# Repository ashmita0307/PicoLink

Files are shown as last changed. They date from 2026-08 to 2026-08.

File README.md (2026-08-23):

# PicoLink
An RP2040-based project for VGA graphics generation and USB composite device implementation.

## Table of Contents

  - [PicoLink](#picolink)
  - [Table of Contents](#table-of-contents)
  - [About The Project](#about-the-project)
  - [Features](#features)
  - [Project Workflow](#project-workflow)
  - [Hardware Used](#hardware-used)
  - [Breadboard Testing](#breadboard-testing)
  - [PCB Model](#pcb-model)
  - [Software Used](#software-used)
  - [Future Work](#future-work)
  - [Contributors](#contributors)
  - [Resources](#resources)
  - [Acknowledgements](#acknowledgements)

## About The Project
**PicoLink** is an RP2040-based project focused on **VGA graphics generation** and **USB communication**. It uses **PIO and DMA** for efficient VGA output and implements a **USB composite device with HID and CDC interfaces**.

## Features

- VGA output using RP2040
- Custom VGA graphics library
- Increased color support
- PIO-based VGA signal generation
- DMA-assisted data transfer
- Custom PCB design
- Space Invaders game
- Pacman game
## Project Workflow

#### Research

* Understanding VGA standards, timing, and signal generation
* Studying the RP2040's PIO and DMA peripherals
* Reviewing existing VGA libraries and RP2040 implementations

#### VGA Graphics Development

* Implementing VGA signal generation using PIO
* Developing a custom VGA graphics library
* Implementing framebuffer-based graphics
* Increasing color support and optimizing memory usage
* Testing VGA output on a monitor

#### PCB Design

* Designing the PicoLink PCB around the RP2040
* Designing the VGA interface and USB connections
* Routing the PCB while considering signal integrity and hardware constraints
* Finalizing the PCB for manufacturing
#### USB Development

* Implementing USB HID functionality
* Implementing USB CDC communication
* Creating and understanding the required USB descriptors
* Integrating HID and CDC as a composite USB device

#### Game Development & Testing

* Developing **Sngpace Invaders & Pacman** using the custom VGA graphics library
* Integrating the game with the PicoLink hardware
* Testing VGA output, USB communication, and overall system performance
* Debugging and optimizing the final implementation

## Hardware Used

| Components | Description |
| --- | --- |
| [RP2040-Mitrocontroller](https://robu.in/product/raspberry-pi-pico/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) | Microcontroller |
| [15-Pin VGA Connector](https://robu.in/product/x0615ft7b1-xkb-15p-female-d-sub-3-d-sub-vga-connectors-rohs/)  | VGA-connector |
| [33O ohm Resistors](https://robu.in/product/330-ohm-1-4w-1206-surface-mount-chip-resistor-pack-of-100/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) | Resistor |

## Breadboard Testing
- View of Breadboard VGA Connections:   
<p align="left">
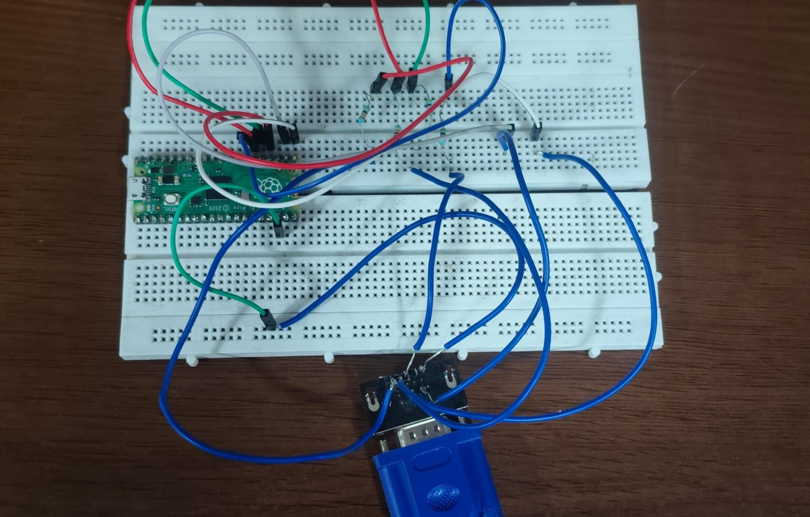
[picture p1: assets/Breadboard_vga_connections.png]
Breadboard VGA Connections
  
</p>

## PCB Model

- View of the PCB Model front and back:       
<table>
  <tr>
    <td align="center">
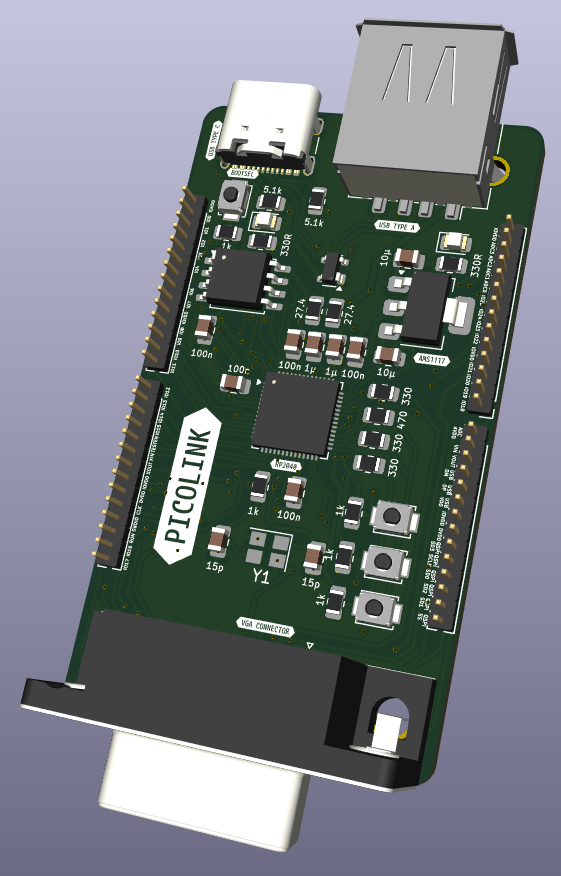
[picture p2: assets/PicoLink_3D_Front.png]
PCB Model Front
      
    </td>
    <td align="center">
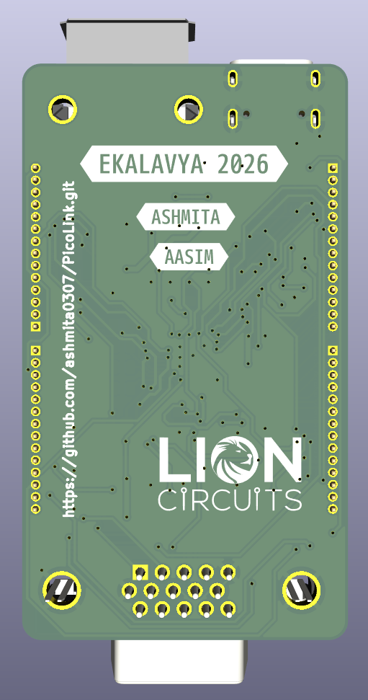
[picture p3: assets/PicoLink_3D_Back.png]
PCB Model Back
      
    </td>
  </tr>
</table>

- View of the PCB Routing - front and back:      

<table>
  <tr>
    <td align="center">
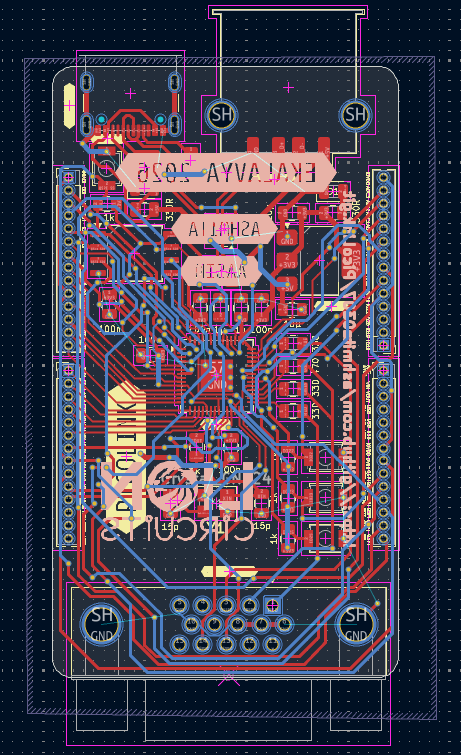
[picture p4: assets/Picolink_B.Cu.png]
      
    </td>
    <td align="center">
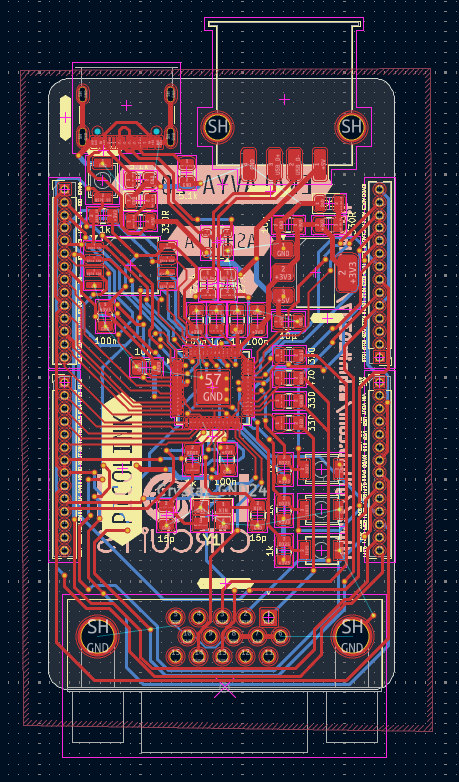
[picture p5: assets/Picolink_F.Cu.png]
      
    </td>
  </tr>
</table>

## Software Used 

- PCB Design - [KiCad 10.0.5](https://www.kicad.org/)
- Software development kit for RP2040 - [Raspberry Pi Pico SDK](https://github.com/raspberrypi/pico-sdk) 

## Future Work
- [ ] Develop a more memory-efficient rendering system
- [ ] Develop more games/examples using the custom graphics library

## Contributors
- [Ashmita Subramanian](https://github.com/ashmita0307)
- [Mohd Aasim](https://github.com/Mohdaasim18)

## Resources

- [razorArnov Github Repository](https://github.com/razorArnov/PICO-VGA-BOARD.git)
- [Phil's lab Kicad Playlist](https://www.youtube.com/watch?v=O-zNn5k5Bn4)
- [Mikeshah's C Programming playlist](https://www.youtube.com/playlist?list=PLvv0ScY6vfd8M-Mi_Vyrg7KgISTW3Sklt)

## Acknowledgements 
- [SRA VJTI](https://sravjti.in/) Eklavya 2026
- Special thanks to our mentors [Omkar Nanajkar](https://github.com/nomkar24), [Moksh Panicker](https://github.com/moxybaba), and all the seniors at SRA, VJTI for their constant support and guidance throughout the project.

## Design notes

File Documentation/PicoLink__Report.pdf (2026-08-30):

# PICOLINK

### Project Report

Mohd Aasim
Ashmita Subramanian

August 2026

# Acknowledgments

We would like to express our deepest gratitude to our mentors, Omkar Nanajkar and Moksh Panicker, whose guidance, technical feedback, and continuous support played a crucial role in the development of PicoLink. Their discussions and reviews helped us understand and implement concepts such as embedded graphics, RP2040 peripherals, PIO-based timing, DMA-driven data transfer, USB device classes, and practical PCB development.

We sincerely thank the SRA-VJTI team for providing us with the opportunity, resources, and support to work on PicoLink and for fostering an environment that encouraged us to explore, learn, and build.

Mohd Aasim
Ashmita Subramanian

# Overview

PicoLink is an embedded graphics and USB project built around the RP2040. The project explores how a low-cost microcontroller can generate a VGA video signal while simultaneously providing USB functionality. The core of the work is the use of the RP2040's Programmable I/O (PIO) blocks and Direct Memory Access (DMA) to generate deterministic video timing and stream pixel data with minimal CPU intervention.
The project began with the study and modification of an existing Pico VGA software stack. The implementation was progressively adapted to support more colour information, while considering the limited SRAM available on the RP2040. The final development direction focused on a practical 16-colour implementation and reliable VGA output.
Alongside VGA generation, PicoLink explores USB composite-device functionality, allowing the RP2040 to act as a USB device with HID and CDC capabilities. This combination makes the platform useful not only as a graphics experiment but also as a compact embedded development and interaction platform.

# Table of Content

### 1. Introduction

1.1 About PicoLink --------------------------------------------------------- 1 1.2 Problem Statement ------------------------------------------------------- 1 1.3 Proposed Solution--------------------------------------------------------- 1

### 2. Custom PCB Layout

2.1 Introduction ------------------------------------------------------------- 2 2.2 List of Components ----------------------------------------------------- 2 2.3 Circuit Connections ------------------------------------------------------ 2-6

### 3. VGA Generation

3.1 Introduction --------------------------------------------------------------- 7 3.2 VGA Signal Components ----------------------------------------------- 7 3.3 VGA Timing -------------------------------------------------------------- 8 3.4 RP2040-Based VGA Generation ------------------------------------ 9 3.5 PIO-Based Signal Generation ---------------------------------------- 9 3.6 Pixel Data and Framebuffer --------------------------------------------- 10 3.7 DMA-Based Pixel Transfer -------------------------------------------- 10-11

### 4. Graphics and Framebuffer

4.1 Introduction -------------------------------------------------------------- 12 4.2 Framebuffer ------------------------------------------------------------- 12 4.3 Pixel Representation ------------------------------------------------- 13 4.4 Resolution and Memory Requirement ---------------------------- 13 4.5 Memory Limitation During Development ------------------------ 14-15 4.6 Graphics Rendering ----------------------------------------------- 15

### 5. USB Implementation

5.1 Introduction ---------------------------------------------------------- 16

5.2 RP2040 USB Interface --------------------------------------------- 16 5.3 USB HID ------------------------------------------------------------- 16 5.4 USB CDC ------------------------------------------------------------ 17 5.5 USB Composite Device -------------------------------------------- 17 5.6 Final USB Composite Implementation ---------------------------- 18 5.7 USB Initialization and HID/CDC Handling ---------------------------- 19

### 6. Development Process

6.1 Week 1–2 Resource Study and Initial PCB Design --------------------- 20 6.2 Week 3–4 Hardware Connections and VGA Library Implementation -21 6.3 Week 5–6 VGA Development and PCB Completion ----------------- 22 -23 6.4 Week 7–8 USB Composite, Game Development and PCB Assembly -24

### 7. Future Scope ------------------------------------------------------------------ 25

### 8. Conclusion -------------------------------------------------------------------- 26

### 9. References ---------------------------------------------------------------- 27

# 1.Introduction

### 1.1 About PicoLink

PicoLink is a project centred on low level embedded graphics and USB device development using the RP2040 microcontroller. Its primary objective is to understand how video timing, pixel generation, memory movement, and USB communication can be implemented close to the hardware level.
The project combines hardware and firmware work. On the hardware side, the RP2040 is interfaced with a VGA connector through resistor based RGB outputs. On the firmware side, PIO state machines generate timing-sensitive VGA signals while DMA is used to move pixel data efficiently.

### 1.2 Problem Statement

Generating a stable VGA signal is timing-sensitive because horizontal synchronization, vertical synchronization, active video intervals, and pixel data must occur at precise times. Performing the complete process directly through software running on the CPU can consume a significant amount of processing time and can make timing less deterministic.
A second challenge is the limited SRAM of the RP2040. Increasing colour depth or storing a complete high-resolution framebuffer rapidly increases memory usage. Therefore, PicoLink requires a balance between resolution, colour depth, framebuffer representation, and the available memory.

### 1.3 Proposed Solution

The proposed solution is to use the RP2040's PIO subsystem as the timing-critical VGA engine. PIO state machines generate synchronization signals and output pixel data at a controlled rate. DMA feeds the required data to the PIO without requiring the processor to manually write every pixel.
For colour generation, the design uses digital RGB lines connected through resistors to the VGA connector. The implementation was explored at higher colour depths, but the final working direction was reduced to a 4-bit, 16-colour configuration to keep the design practical within the RP2040's memory limitations.

# 2.Custom PCB Layout

### 2.1 Introduction

The PicoLink PCB is designed around the RP2040 microcontroller and integrates the major hardware required for USB communication, VGA output, external flash storage, power regulation, user input, and hardware expansion. The custom board combines these modules into a single compact platform, providing the required interfaces for the PicoLink system.

### 2.2 List of Components

RP2040: Main microcontroller responsible for processing and control. W25Q32JVSS: External QSPI flash memory.
USB Type-C: Provides 5 V power and USB data connection. AMS1117-3.3: Converts 5 V input to regulated 3.3 V.
VGA Connector: Provides RGB, HSYNC and VSYNC output.

### 2.3 Circuit Connections

### 2.3.1 RP2040 Connections

The RP2040 acts as the main controller of the PicoLink PCB. Its GPIO pins are connected to the VGA interface, QSPI flash memory, USB interface, push buttons and expansion headers. The controller is powered from the 3.3 V supply and is provided with the required clock and decoupling circuitry. configuration to keep the design practical within the RP2040's memory limitations.

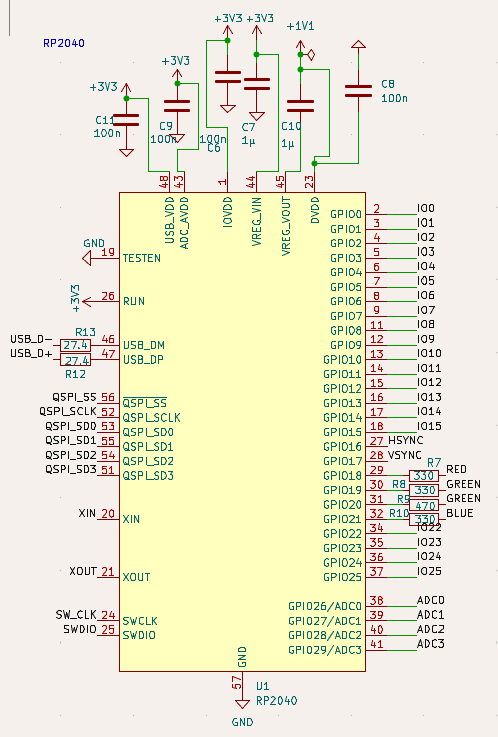
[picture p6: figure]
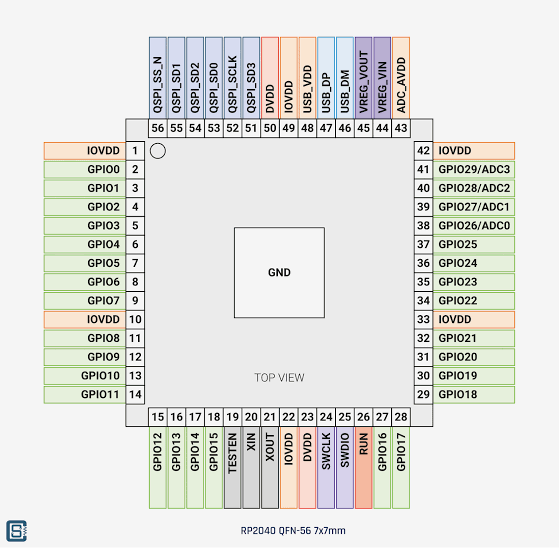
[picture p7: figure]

Figure 2.1 RP2040 Pinout Diagram

Figure 2.2 RP2040 Schematic Connections

### 2.3.2 USB Connections

The PicoLink PCB provides both USB Type-C and USB Type-A interfaces. The USB Type-C connector is used for the primary USB connection and also provides the 5 V input supply to the board. The USB data lines are connected to the RP2040 for USB communication.

The USB Type-A connector provides an additional USB interface for connecting external USB devices. Both connectors are incorporated into the design to provide flexibility for different USB connection and testing requirements.

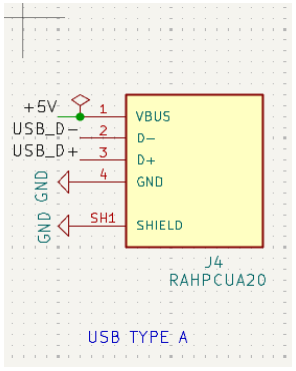
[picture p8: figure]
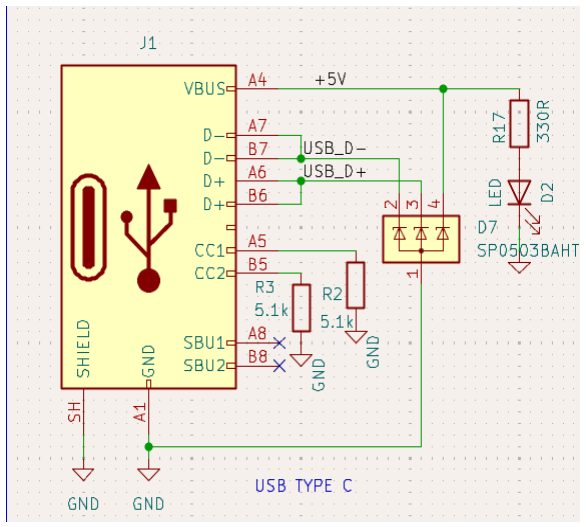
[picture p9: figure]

Figure 2.3 USB C Connections | Figure 2.4 USB A Connections

### 2.3.3 VGA Connections

The PicoLink PCB provides a VGA interface for video output generated by the RP2040. The interface includes separate signals for the Red, Green, and Blue colour channels, along with HSYNC and VSYNC signals for controlling the display timing. The VGA signals are routed from the assigned RP2040 GPIO pins to the VGA connector through the corresponding resistor network. The VGA connector follows the standard 15-pin D-sub (DE-15) pinout, where pins 1, 2, and 3 are assigned to the Red, Green, and Blue signals respectively, while pins 13 and 14 carry the HSYNC and VSYNC signals. The connector also includes ground connections associated with the RGB and synchronization signals to provide appropriate signal return paths.

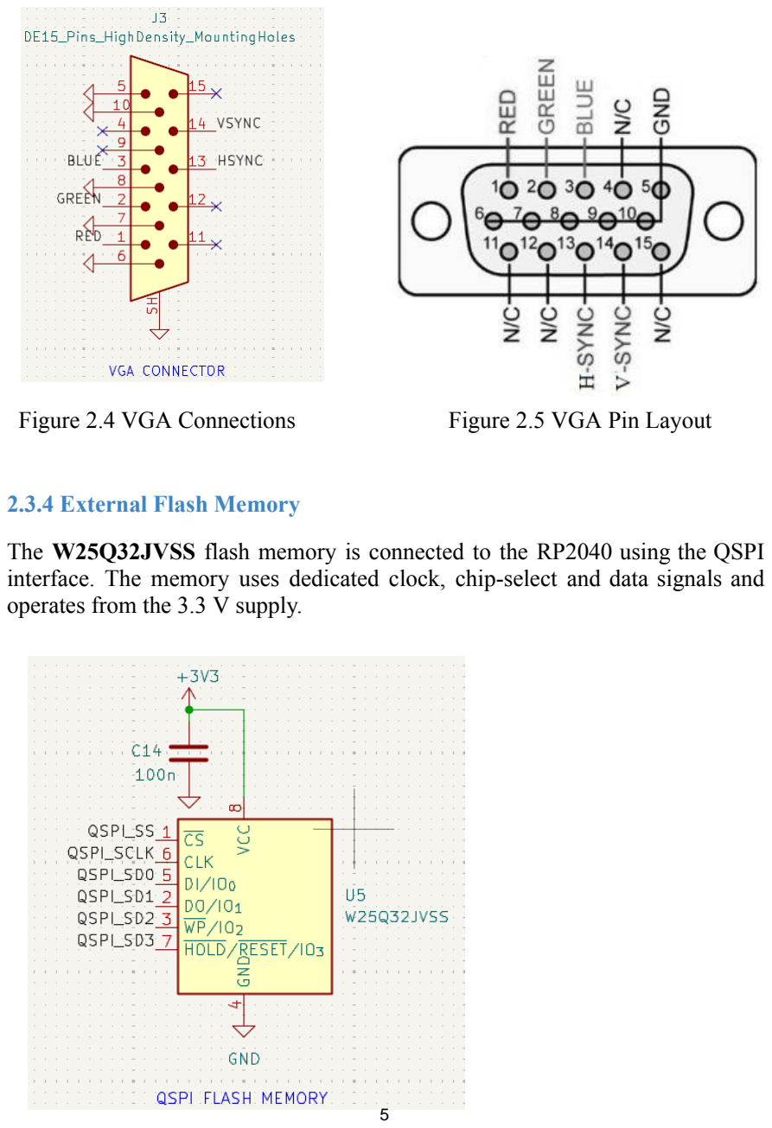
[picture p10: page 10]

Figure 2.4 VGA Connections | Figure 2.5 VGA Pin Layout

### 2.3.4 External Flash Memory

The W25Q32JVSS flash memory is connected to the RP2040 using the QSPI interface. The memory uses dedicated clock, chip-select and data signals and operates from the 3.3 V supply.

Figure 2.6 QSPI flash memory connections

### 2.3.5 Power Supply

The PCB receives 5 V through the USB interface. The AMS1117-3.3 regulator converts this input into a regulated 3.3 V supply for the RP2040 and other components. Capacitors are provided around the regulator for stable operation, along with an LED to indicate the presence of the supply.

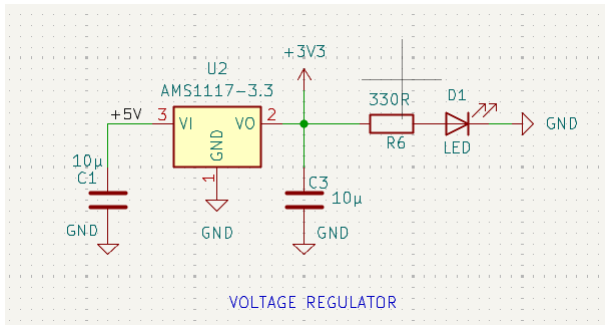
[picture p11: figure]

Figure 2.7 3.3 V voltage regulator circuit

### 2.3.5 Clock and Push Buttons

A crystal is connected to the XIN and XOUT pins of the RP2040 to provide the required clock reference. The PCB also contains push buttons connected to GPIO pins, which can be used for control and testing purposes.

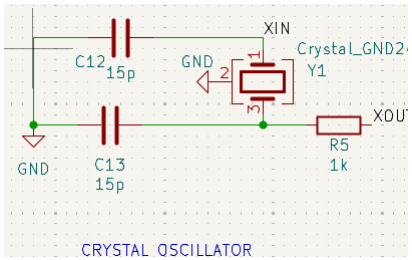
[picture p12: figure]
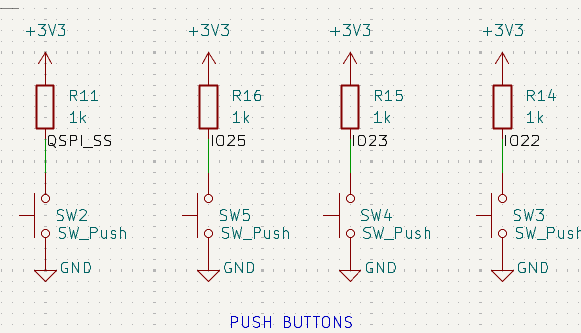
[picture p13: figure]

Figure 2.8 Crystal oscillator circuit | Figure 2.9 Push Buttons

# 3.VGA Generation

### 3.1 Introduction to VGA

VGA generation is one of the main functions implemented in the PicoLink project. The RP2040 is used to generate the video signals required by a VGA display, including the RGB colour signals and the horizontal and vertical synchronization signals. Instead of using a dedicated VGA controller, the project makes use of the RP2040's programmable hardware resources to generate the required timing and pixel data.

The VGA output is generated by coordinating the pixel data with the synchronization signals.

### 3.2 VGA Signal Components

A VGA video signal consists of three colour channels and two synchronization signals. The three colour channels are Red, Green, and Blue (RGB), which determine the colour of each pixel. The two timing signals are HSYNC and VSYNC.

HSYNC is associated with the timing of each horizontal line of the display, while VSYNC controls the transition between successive frames. The RGB signals are generated during the active display region, while the synchronization signals maintain the timing required by the monitor.

For PicoLink, these signals are generated using dedicated RP2040 GPIO connections and are routed to the VGA connector on the custom PCB.

### 3.3 VGA Timing

A VGA display does not continuously interpret the RGB signals as visible pixels. Each horizontal line follows a defined timing sequence consisting of an active video region and timing intervals associated with synchronization.

Similarly, a complete frame consists of multiple horizontal lines followed by the vertical synchronization sequence. Therefore, the VGA generator has to maintain accurate timing for both the horizontal and vertical directions.

The PicoLink implementation generates these timing signals continuously so that the display can determine the current position within the frame and correctly associate the generated pixel data with its position on the screen.

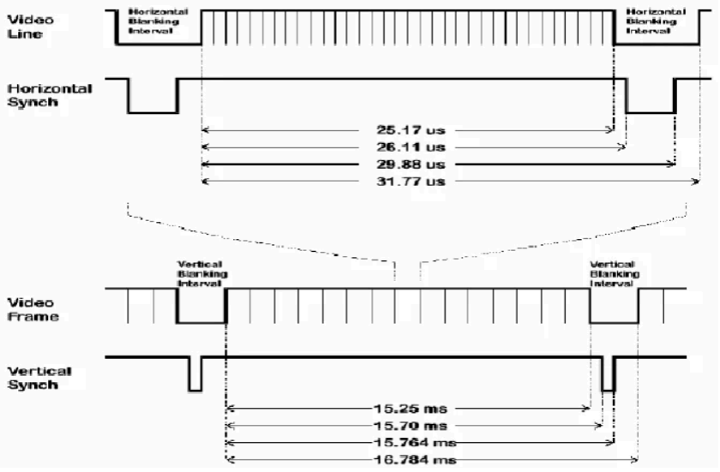
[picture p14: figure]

Figure 3.1 VGA Timing Diagram

### 3.4 PIO-Based Signal Generation

The RP2040 includes a Programmable I/O (PIO) subsystem that can execute small dedicated programs independently of the main processor. This makes PIO suitable for applications where signals have to be generated with predictable timing.

In PicoLink, PIO is used as part of the VGA generation process. Instead of making the main CPU manually control every timing transition, the PIO state machines handle time-critical signal generation. This allows the processor to perform other tasks while the video hardware maintains the required timing.

The PIO program controls the sequence in which the synchronization and pixel-related signals are produced. The timing of these operations is determined by the PIO instructions and its clock configuration.

### 3.5 Pixel Data and Framework

To display graphics, the VGA generator requires pixel information corresponding to the current position on the screen. PicoLink uses a framebuffer-based approach in which pixel data is stored in memory and read during video generation.

Each location in the framebuffer represents the colour information of a corresponding pixel. During display generation, the stored pixel information is converted into the appropriate RGB output signals.

The framebuffer size depends on both the display resolution and the number of bits used to represent each pixel. Increasing either the resolution or colour depth increases the required memory. This became an important consideration during PicoLink development because the available RAM of the RP2040 places a practical limit on the size of a directly stored framebuffer.

### 3.6 Color Generation

The RGB output is generated by combining the digital signals assigned to the red, green and blue channels. Different combinations of logic levels produce different colour values at the VGA interface.

The number of available colours depends on the number of bits allocated to the RGB channels. Increasing the colour depth provides more possible colours but also increases the amount of memory required when a framebuffer is used.

During PicoLink development, colour depth and display resolution were therefore considered together because both directly affect the memory requirement of the framebuffer.

### 3.7 VGA Signal Verification

After implementing the VGA generation system, the generated synchronization signals were tested using an oscilloscope. HSYNC and VSYNC were observed directly to verify that the RP2040 was producing the required periodic signals.

The oscilloscope measurements provide a hardware-level verification of the signal generation rather than relying only on the final monitor output. The VGA output was subsequently tested with a display to verify that the generated synchronization and colour signals were correctly interpreted.

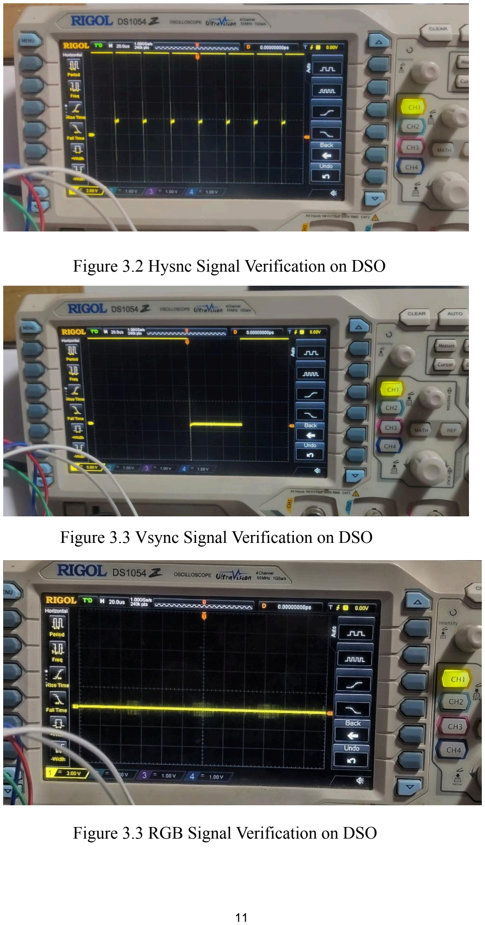
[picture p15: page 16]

Figure 3.2 Hysnc Signal Verification on DSO

Figure 3.3 Vsync Signal Verification on DSO

Figure 3.3 RGB Signal Verification on DSO

# 4. Graphics and Framebuffer

### 4.1 Introduction

The graphics system of PicoLink is responsible for storing and displaying pixel information on the VGA output. The RP2040 generates the required VGA timing signals while the graphics data is stored in memory and supplied to the video-generation pipeline.

A framebuffer is used to represent the image that is displayed on the screen. Each location in the framebuffer corresponds to a pixel, and the value stored at that location determines the colour that is produced on the VGA output.

The implementation of the framebuffer required careful consideration of the available memory of the RP2040, since the amount of memory required increases with both display resolution and colour depth.

### 4.2 Frame Buffer

The framebuffer is a region of memory that stores the pixel data for a complete display image. Instead of generating the graphics directly at the VGA output, the required image can first be constructed in the framebuffer and then read during the display process.

For a framebuffer with width (W), height (H), and (B) bits per pixel, the required memory can be calculated as:

Framebuffer Memory=W×H×8B

Framebuffer Memory =640×480×84=307200×0.5

=153600 bytes

This shows why framebuffer size becomes an important limitation on a microcontroller with limited internal RAM.

### 4.3 Pixel Representation

Each pixel in the framebuffer is represented using a fixed number of bits. These bits determine the colour information that is eventually sent to the RGB outputs.

In the PicoLink implementation, a 4-bit colour representation was used, allowing:

2^4 = 16 different colour values.

The pixel data is therefore represented using a compact format rather than storing a complete multi-byte colour value for every pixel. This reduces the memory required by the framebuffer while still providing multiple colour combinations for the VGA output.

### 4.4 Resolution and Memory Requirement

The framebuffer memory requirement is directly dependent on the selected display resolution. Increasing the horizontal or vertical resolution increases the total number of pixels that have to be stored.

Resolution | Pixels
320 x 240 | 76,800
640 x 480 | 307,200

At the same colour depth, the 640 × 480 framebuffer requires four times as many pixel locations as a 320 × 240 framebuffer.

Similarly, increasing the number of bits used for each pixel increases the amount of memory required per pixel. Therefore, resolution and colour depth have to be selected together when designing a framebuffer-based graphics system for a resource-constrained microcontroller.

### 4.5 Graphics Rendering

Graphics are generated by modifying the values stored in the framebuffer. A graphics operation can change one or more pixel locations, after which the VGA generation system reads the updated pixel information during the corresponding display period.

This provides a separation between the graphics generation and the physical VGA signal generation. The application determines what should appear on the screen, while the video-generation system is responsible for transmitting the stored pixel information with the appropriate timing.

This approach also makes it possible to implement different graphics operations such as drawing pixels, lines, shapes, text, and other visual elements using the same framebuffer.

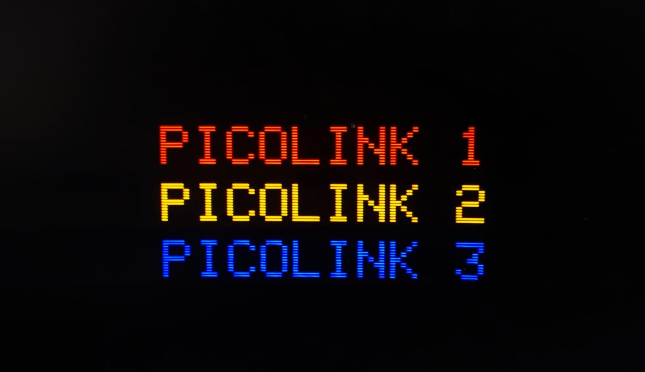
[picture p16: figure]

Figure 4.1 Graphics Displayed using PicoLink framebuffer

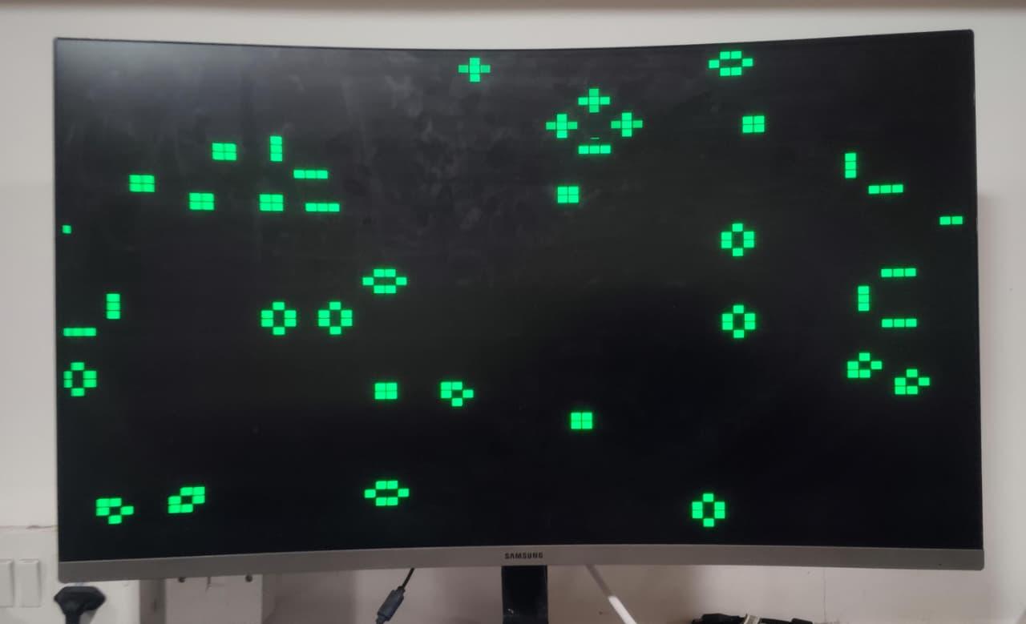
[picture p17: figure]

Figure 4.2 : Graphics Displayed using PicoLink framebuffer

### 4.6 Memory Limitations During Development

One of the major challenges encountered during the PicoLink graphics implementation was the limited RAM available on the RP2040.

An initial implementation attempted to use a 640 × 480 framebuffer with higher colour information. The resulting memory requirement became too large for the available RAM, leading to memory and linker limitations during compilation.

This demonstrated an important trade-off in the design: increasing resolution and colour depth improves the visual output but simultaneously increases memory consumption.

The implementation was therefore modified to use a more memory-efficient pixel representation. The final implementation used 4-bit colour, providing 16 colours, while retaining the required VGA output functionality.

# 5. USB Implementation

### 5.1 Introduction

USB communication is another important part of the PicoLink project. The RP2040 provides a built-in USB interface that can be used to communicate with a host computer and to implement different USB device classes.

In PicoLink, the USB interface is used to provide communication between the microcontroller and the host system. The implementation combines multiple USB functions into a single device, allowing the board to perform different types of communication through one USB connection.

### 5.2 RP2040 USB Interface

The RP2040 contains an integrated USB 1.1 controller and PHY, allowing USB communication without requiring a separate USB-to-UART converter for the main USB interface.

The USB D+ and D− signals from the USB connector are connected directly to the USB interface of the RP2040. The USB controller handles the low-level communication with the host, while the firmware defines how the device behaves once it is connected.

### 5.3 USB HID

Human Interface Device (HID) is a USB device class commonly used for peripherals such as keyboards, mice and controllers. HID devices can communicate with the host using standardized USB descriptors and reports.

In PicoLink, the HID interface can be used to make the RP2040 appear to the host computer as a USB input device. The firmware controls the data contained in the HID reports and determines how the host interprets the received information.

This provides a way for PicoLink to interact with the host without requiring a dedicated application-specific USB driver.

### 5.4 USB CDC

The Communication Device Class (CDC) provides a standardized method for implementing serial-style communication over USB. A CDC interface allows the host computer to communicate with the RP2040 through a virtual serial connection.

In PicoLink, the CDC interface can be used for communication between the firmware and the host computer. It is particularly useful during development because messages and debugging information can be exchanged without requiring a separate physical serial connection.

### 5.5 Composite USB Device

PicoLink combines the HID and CDC interfaces into a composite USB device. This allows a single USB connection to expose more than one USB function to the host.

After connecting PicoLink to a computer, the host can identify the different interfaces provided by the device. The HID interface handles input-related communication, while the CDC interface provides serial-style communication.

The composite approach allows multiple functions to coexist without requiring separate USB connectors for each interface.

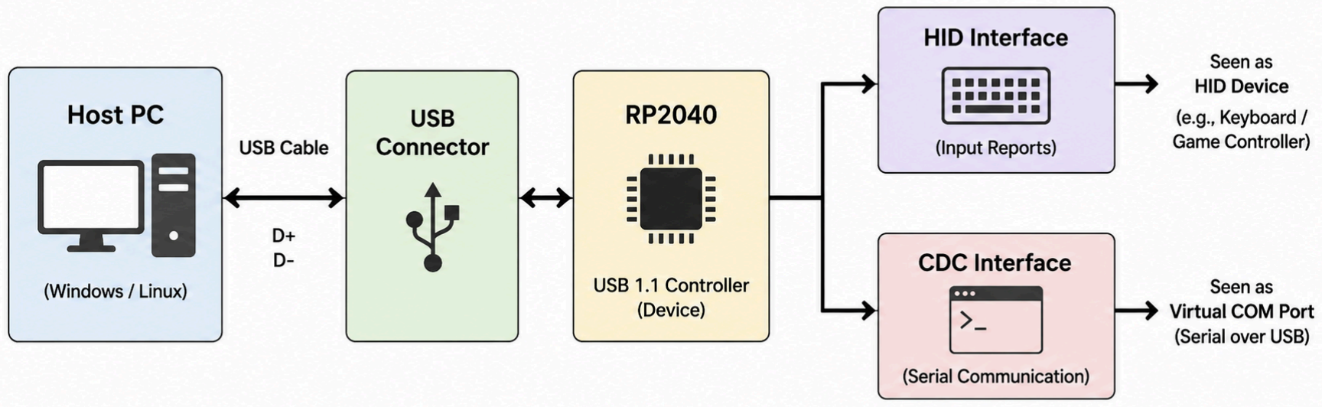
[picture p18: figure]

Figure 4.1 Graphics Displayed using PicoLink framebuffer Figure 5.1 : Block Diagram of USB Composite Device

### 5.6 Final USB Composite Implementation

The Final USB implementation of PicoLink combines HID and CDC functionality within a single composite USB device. Both interfaces are implemented through the RP2040's USB peripheral and are accessible through a single physical USB connection to the host computer.

The HID interface provides the device-side functionality required for HID-based communication, while the CDC interface provides a virtual serial communication channel between the PicoLink board and the host system. The composite configuration allows both interfaces to operate simultaneously without requiring separate USB connections.

The final implementation was integrated into the PicoLink firmware and verified on the host computer. The resulting device exposes both HID and CDC interfaces, demonstrating the successful integration of multiple USB device classes into the PicoLink system.

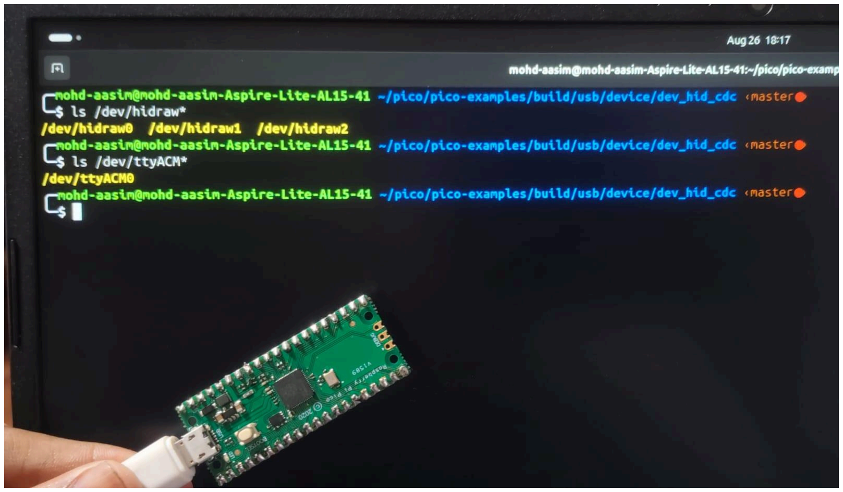
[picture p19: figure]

Figure 5.2 : USB Composite Interface — HID and CDC

### 5.6 USB Initilization and HID/CDC Handling

PicoLink uses the TinyUSB stack to initialize and manage USB communication. The firmware handles USB events using tud_task(), while CDC manages serial data communication and HID handles input reports. Both interfaces are serviced within the same main loop, allowing them to work simultaneously over a single USB connection.

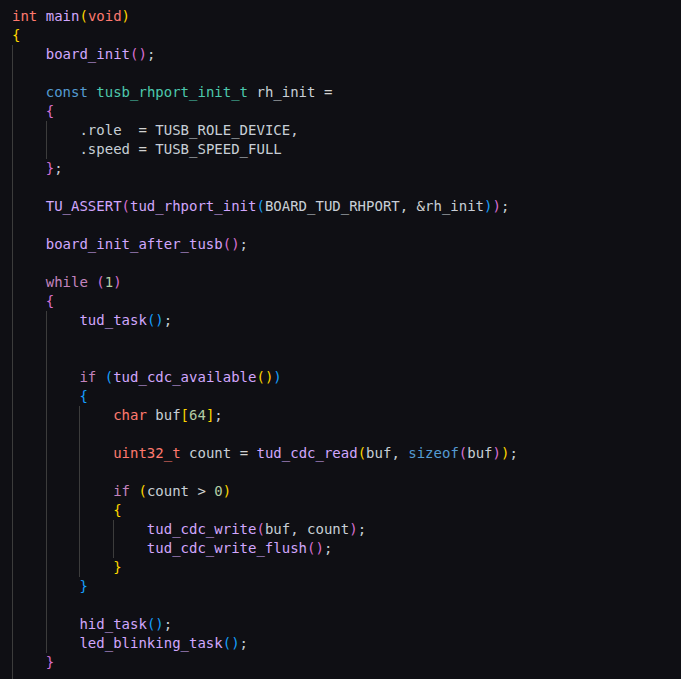
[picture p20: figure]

Figure 5.2 : USB Initialization

# 6.Development Process

The development of PicoLink was carried out over a period of two months, with the work divided into four biweekly phases. Each phase focused on a specific set of hardware and software tasks, gradually taking the project from initial learning and PCB design to VGA implementation, game development, USB integration, and final PCB assembly.

### 6.1 Week 1–2 — Resource Study and Initial PCB Design

During the first two weeks, the focus was on building the technical foundation required for the PicoLink project. Resources related to C programming, FreeRTOS, and PCB design were studied to understand the software and hardware concepts required for the project.

Alongside this learning phase, the requirements of the PicoLink hardware were analyzed and an initial RP2040-based PCB design was developed. The schematic was prepared by selecting the required components and planning their connections according to the intended functionality of the board.

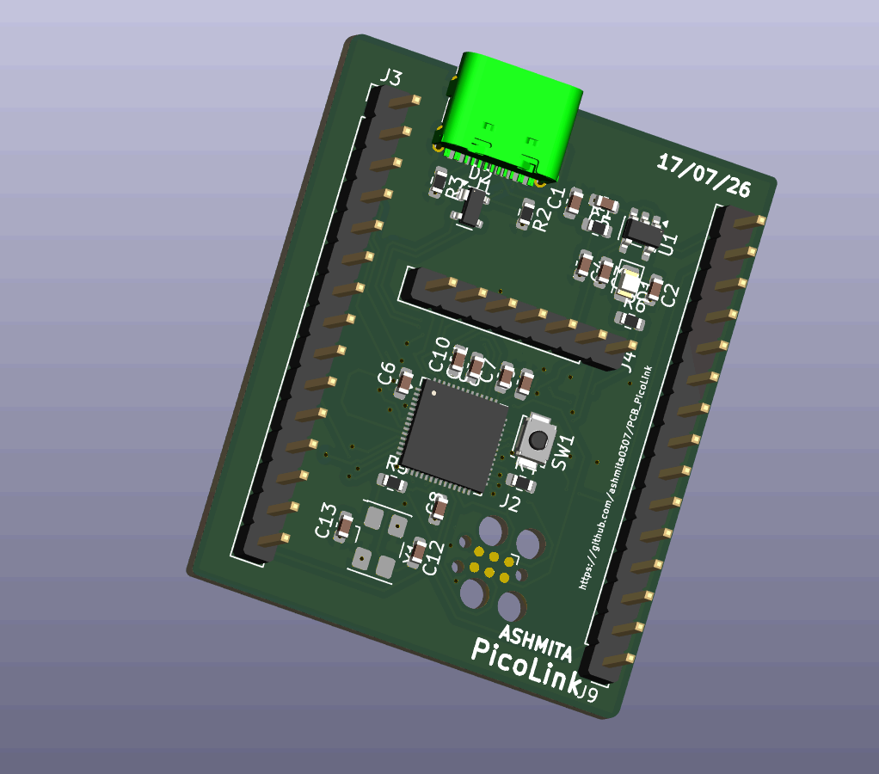
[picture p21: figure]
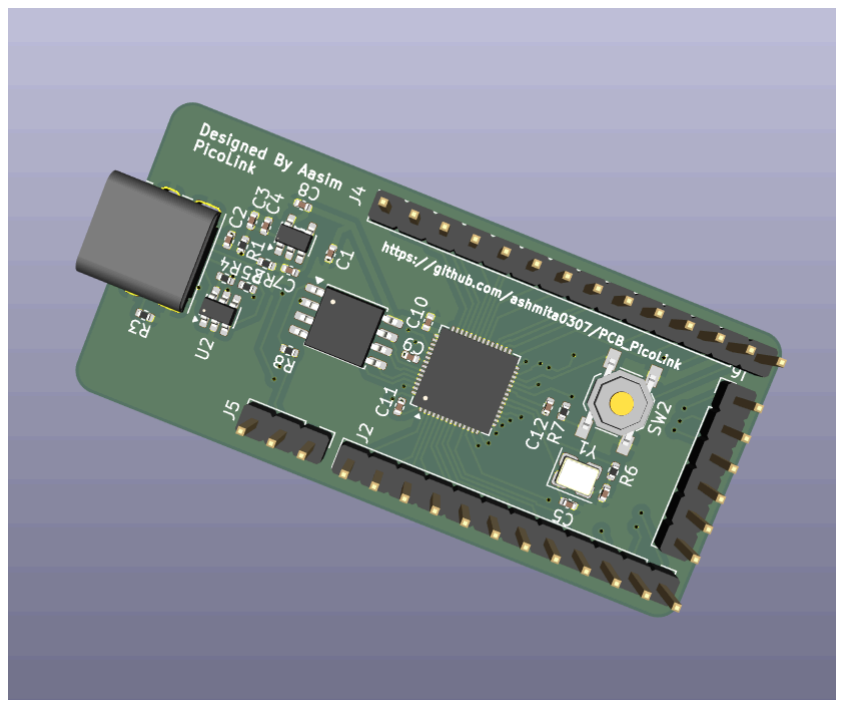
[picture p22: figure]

Figure 6.1 PCB Design-(a) | Figure 6.2 RP2040 PCB-(b)

### 6.2 Week 3–4 — Hardware Connections and VGA Library Implementation

During the third and fourth weeks, the required RP2040 hardware connections were implemented on a breadboard as an initial prototype. The connections between the RP2040 and the VGA interface were established according to the planned design, allowing the circuit to be tested before moving to the custom PCB.

The VGA library was then implemented to generate video output from the RP2040. The existing library was studied to understand its structure and the method used for VGA signal generation. It was then adapted to work with the PicoLink hardware and its assigned GPIO connections.

This phase resulted in the first working VGA output on the breadboard, providing the foundation for further development of the graphics system and subsequent PCB implementation.

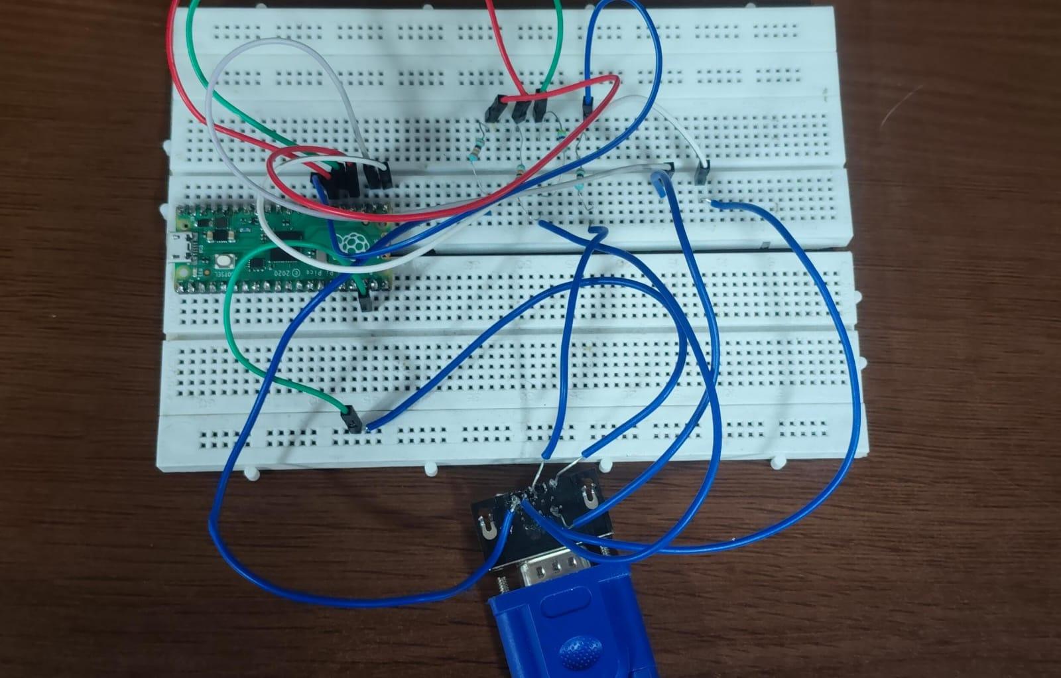
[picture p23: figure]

Figure 6.3 : PicoLink VGA Breadboard Connections

### 6.3 Week 5–6 — VGA Development and PCB Completion

During the fifth and sixth weeks, the focus shifted towards improving the VGA implementation and developing an application using the graphics system. Another VGA library was studied and implemented to explore an alternative approach to VGA generation. Along with this, the firmware for the PicoLink system was developed to control the implemented hardware and video output.

After establishing the graphics functionality, a Space Invaders game was developed as an application to demonstrate the VGA graphics capabilities of PicoLink. This provided a practical way to verify the graphics rendering and interaction between the firmware and the VGA output.

In parallel, the PicoLink PCB design was completed in KiCad, including the required component placement, connections, and routing for the final board.

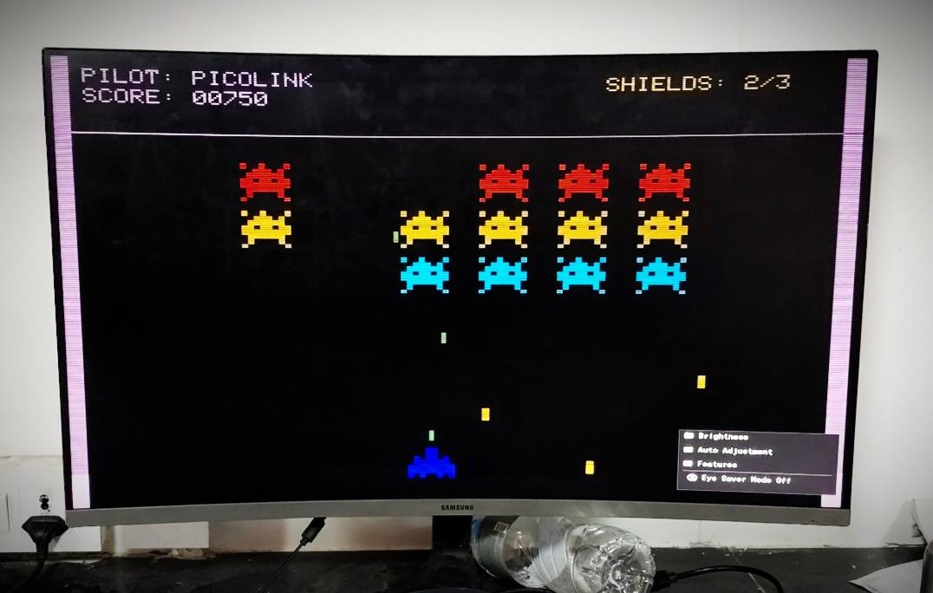
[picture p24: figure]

Figure 6.4 : Space invader’s Implementation

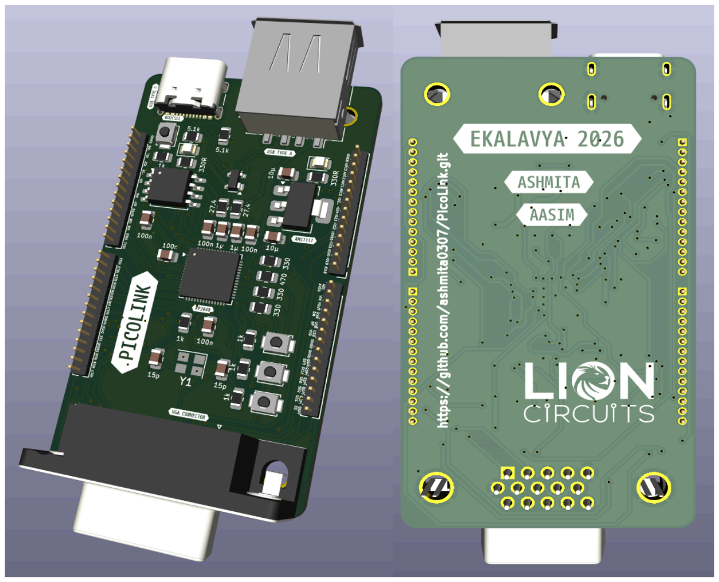
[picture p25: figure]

Figure 6.5 : Final PicoLink PCB Design

### 6.4 Week 7–8 — USB Composite, Game Development and PCB Assembly

During the seventh and eighth weeks, the focus was on completing the remaining PicoLink features and moving towards the final hardware implementation. The USB functionality was extended by implementing HID and CDC as a composite USB device, allowing both interfaces to operate through the same USB connection.

The graphics system was further demonstrated by developing a second game, Pac-Man, using the PicoLink VGA output and graphics capabilities. This provided another practical application of the implemented graphics system.

Alongside the software development, the completed PCB was assembled and the hardware implementation was documented. The assembly process included populating the board with the required components and preparing the assembled PCB for subsequent hardware testing and verification.

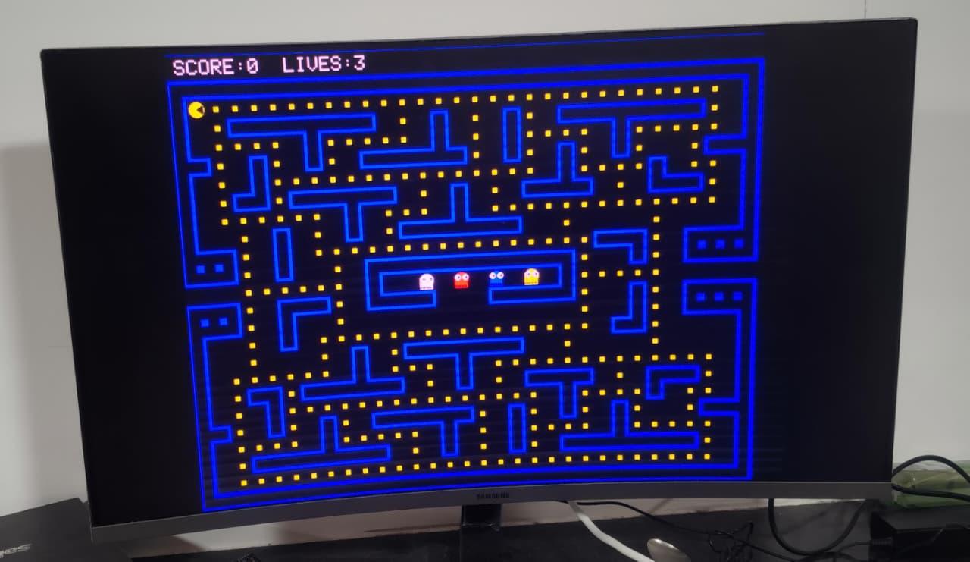
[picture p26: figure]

Figure 6.5 : Pacman Implementation

Figure 6.6 : Final PicoLink PCB

# 7. Future Scope

The PicoLink platform can be further developed by improving its graphics capabilities, USB functionality, and overall hardware design. The modular nature of the RP2040-based system provides scope for extending the existing implementation and exploring more advanced applications.

### 7.1 Higher Resolution and Colour Depth

The graphics system can be optimized to support higher display resolutions and greater colour depth. More memory-efficient rendering techniques, such as scanline-based rendering, could reduce framebuffer memory requirements and allow better visual output within the RP2040's memory constraint

### 7.2 Advanced Graphics

The existing graphics system can be extended with additional graphics primitives, improved text rendering, sprites, animations, and more complex graphical applications. This could allow PicoLink to support a wider range of games and interactive applications.

### 7.3 More Applications and Games

The PicoLink graphics platform can be used to develop additional games and interactive applications beyond Space Invaders and Pac-Man. This would provide further opportunities to evaluate the performance and capabilities of the graphics syst

### 7.4 Optimized Video Pipeline

The VGA pipeline can be further optimized by improving the interaction between PIO, DMA, and framebuffer memory. Better utilization of these hardware resources could reduce CPU overhead and provide smoother graphics generation.

# 8. Conclusion

The PicoLink project provided practical experience in designing and developing an embedded graphics system using the RP2040. Over the course of the project, VGA generation was implemented by combining PIO-based timing, DMA-driven pixel transfer, and framebuffer-based graphics, allowing the system to generate a functional VGA output.

The project also involved developing a practical 4-bit colour implementation with 16 colours, taking into consideration the limited SRAM available on the RP2040. The graphics system was further demonstrated through applications such as Space Invaders and Pac-Man, providing a practical demonstration of the implemented VGA and graphics functionality.

Alongside the graphics system, USB HID and CDC were integrated as a composite USB device, allowing multiple USB interfaces to operate through a single connection. The hardware development progressed from an initial breadboard prototype to the design, completion, and assembly of a custom PicoLink PCB.

Overall, PicoLink provided hands-on experience in embedded C programming, RP2040 peripherals, PIO, DMA, VGA signal generation, framebuffer management, USB device development, PCB design, and hardware debugging. The project also highlighted the importance of balancing system performance with the hardware resources available in an embedded platform.

# 9. References

1. Raspberry Pi Ltd., RP2040 Datasheet, Raspberry Pi, 2024. RP2040 Datasheet (https://pip-assets.raspberrypi.com/categories/610-raspberry-pi-pico/documents/RP-008307-DS-2-pico-datasheet.pdf)
2. razorArnov, PICO-VGA-BOARD — vga_graphics.cpp, GitHub. The file was used as a reference for the VGA graphics implementation. PICO-VGA-BOARD — vga_graphics.cpp (https://github.com/razorArnov/PICO-VGA-BOARD/blob/main/vga_graphics.cpp?utm_source=chatgpt.com)
3. C Programming Series, YouTube playlist. Used during the initial study of C programming. C Programming Series (https://www.youtube.com/playlist?list=PLvv0ScY6vfd8M-Mi_Vyrg7KgISTW3Sklt&utm_source=chatgpt.com)
4. Introduction to RTOS, YouTube playlist. Used for studying RTOS concepts during the initial learning phase. Introduction to RTOS (https://www.youtube.com/playlist?list=PLEBQazB0HUyQ4hAPU1cJED6t3DU0h34bz&utm_source=chatgpt.com)
5. VGA/RP2040 Related Tutorial, YouTube. Used as a reference during the development and implementation of the VGA system. VGA/RP2040 Tutorial

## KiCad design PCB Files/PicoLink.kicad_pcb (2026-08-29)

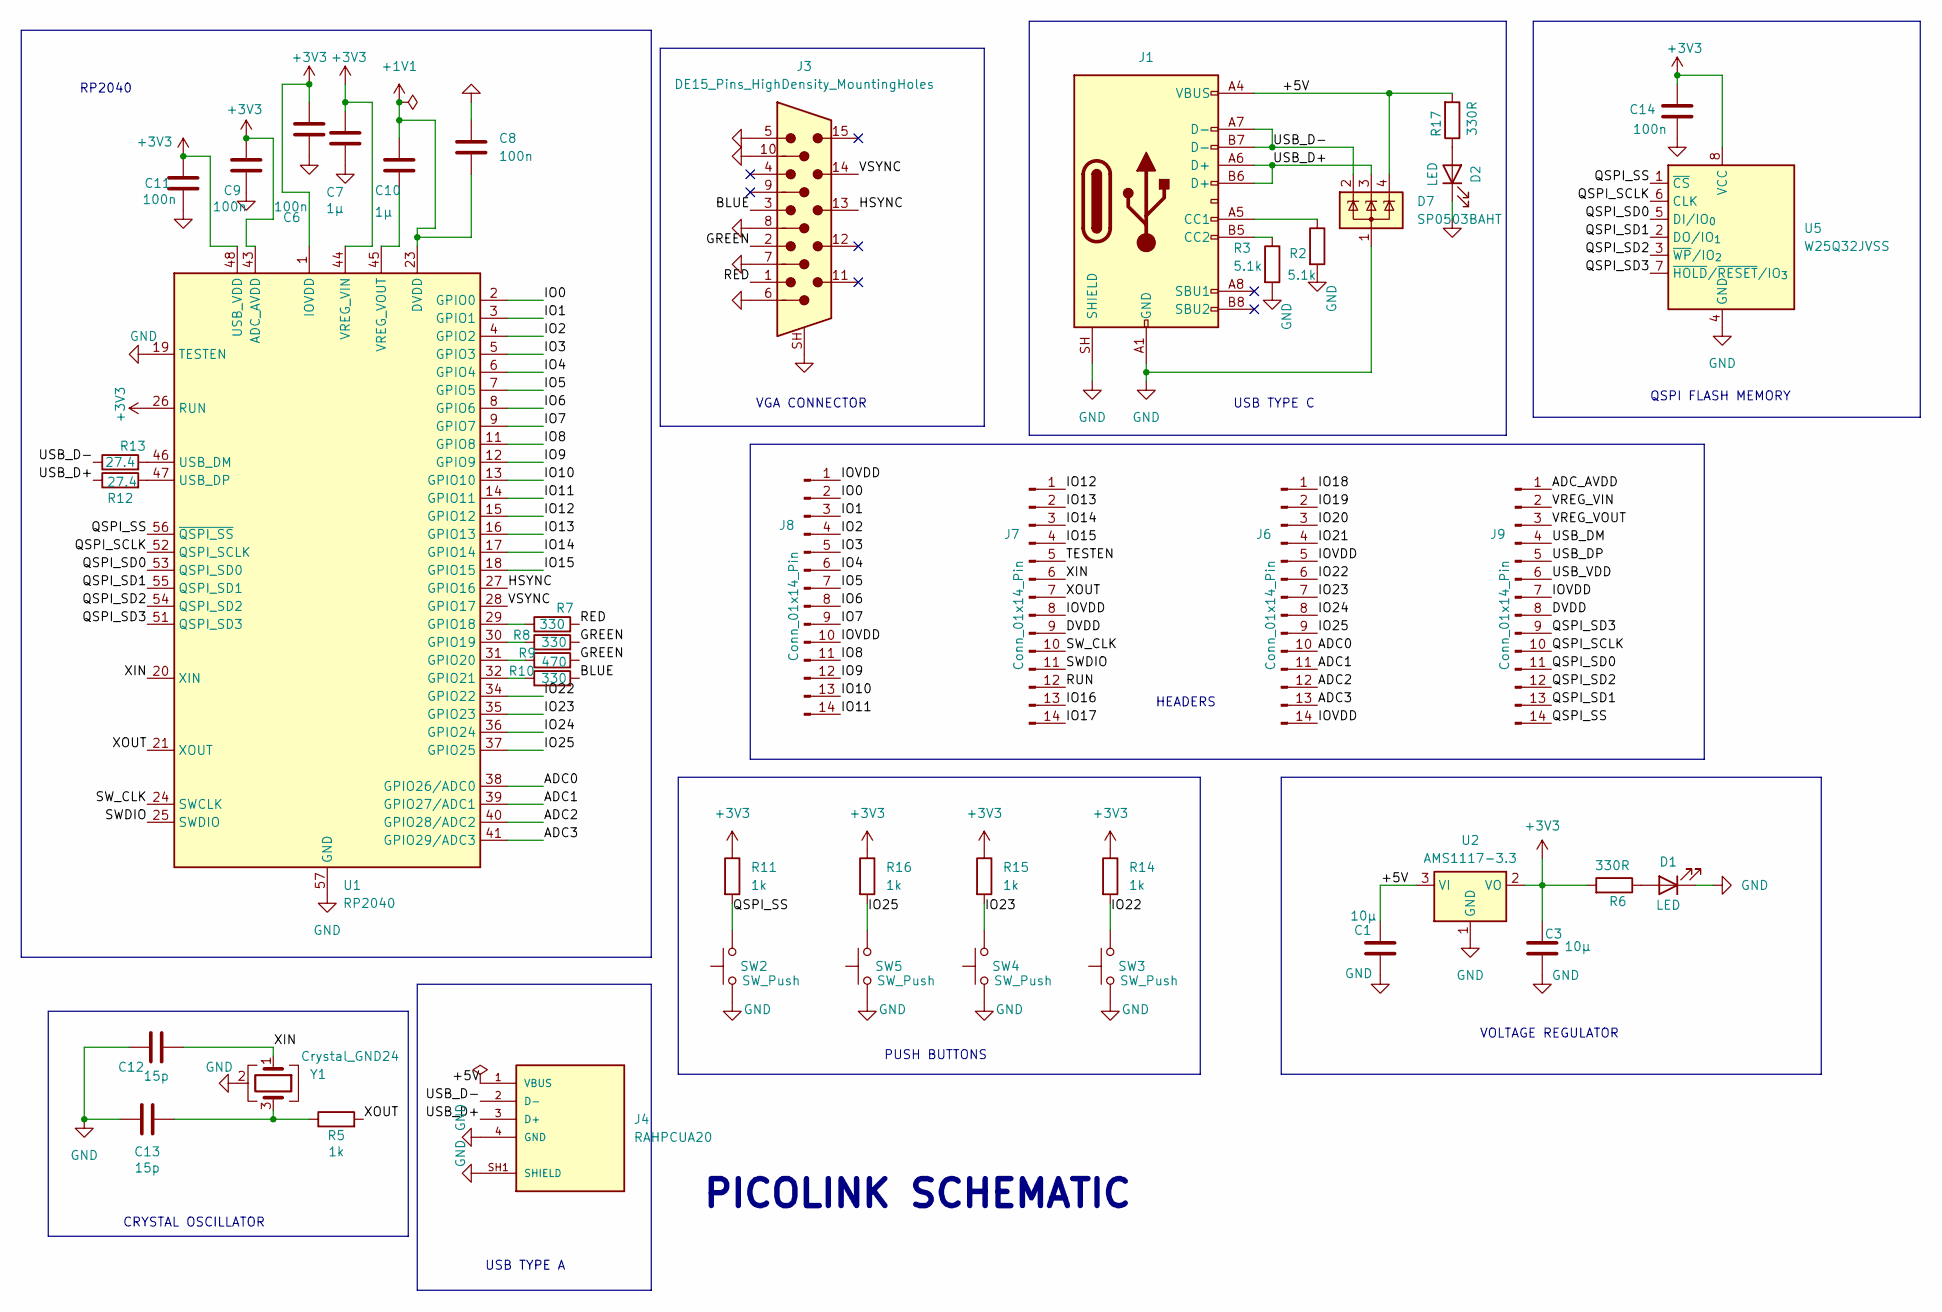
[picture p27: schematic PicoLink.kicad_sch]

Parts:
C1, C3: 10µ; C_0805_2012Metric
C6, C8, C9, C11, C14: 100n; C_0805_2012Metric
C7, C10: 1µ; C_0805_2012Metric
C12, C13: 15p; C_0805_2012Metric
D1, D2: LED; LED_0805_2012Metric
D7: SP0503BAHT; SOT-143
J1: USB_C_Receptacle_USB2.0_16P; USB_C_Receptacle_GCT_USB4105-xx-A_16P_TopMnt_Horizontal
J3: DE15_Pins_HighDensity_MountingHoles; DSUB-15-HD_Socket_Horizontal_P2.29x1.90mm_EdgePinOffset3.03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
J4: RAHPCUA20; USB_A_TE_292303-7_Horizontal; PARTREV A
J6, J7, J8, J9: Conn_01x14_Pin; PinHeader_1x14_P1.27mm_Vertical
R2, R3: 5.1k; R_0805_2012Metric
R5, R11, R14, R15, R16: 1k; R_0805_2012Metric
R6, R17: 330R; R_0805_2012Metric
R7, R8, R10: 330; R_0805_2012Metric
R9: 470; R_0805_2012Metric
R12, R13: 27.4; R_0805_2012Metric
SW2, SW3, SW4, SW5: SW_Push; SW_SPST_B3U-1000P
U1: RP2040; QFN-56-1EP_7x7mm_P0.4mm_EP3.2x3.2mm
U2: AMS1117-3.3; SOT-223-3_TabPin2
U5: W25Q32JVSS; SOIC-8_5.3x5.3mm_P1.27mm
Y1: Crystal_GND24; Crystal_SMD_Abracon_ABM8AIG-4Pin_3.2x2.5mm

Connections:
+1V1: C8.2, C10.1, U1.23 (DVDD), U1.50 (DVDD)
+3V3: C3.1, C6.1, C7.1, C9.1, C11.1, C14.1, R6.2, R11.1, R14.1, R15.1, R16.1, U1.1 (IOVDD), U1.10 (IOVDD), U1.22 (IOVDD), U1.26 (RUN), U1.33 (IOVDD), U1.42 (IOVDD), U1.43 (ADC_AVDD), U1.44 (VREG_VIN), U1.48 (USB_VDD), U1.49 (IOVDD), U2.2 (VO), U5.8 (VCC)
/+5V: C1.1, D7.4 (K), J1.A4 (VBUS), J1.A9 (VBUS), J1.B4 (VBUS), J1.B9 (VBUS), J4.1 (VBUS), R17.2, U2.3 (VI)
/ADC0: J6.10, U1.38 (GPIO26/ADC0)
/ADC1: J6.11, U1.39 (GPIO27/ADC1)
/ADC2: J6.12, U1.40 (GPIO28/ADC2)
/ADC3: J6.13, U1.41 (GPIO29/ADC3)
/ADC_AVDD: J9.1
/BLUE: J3.3, R10.2
/DVDD: J7.9, J9.8
/GREEN: J3.2, R8.2, R9.2
/HSYNC: J3.13, U1.27 (GPIO16)
/IO0: J8.2, U1.2 (GPIO0)
/IO1: J8.3, U1.3 (GPIO1)
/IO2: J8.4, U1.4 (GPIO2)
/IO3: J8.5, U1.5 (GPIO3)
/IO4: J8.6, U1.6 (GPIO4)
/IO5: J8.7, U1.7 (GPIO5)
/IO6: J8.8, U1.8 (GPIO6)
/IO7: J8.9, U1.9 (GPIO7)
/IO8: J8.11, U1.11 (GPIO8)
/IO9: J8.12, U1.12 (GPIO9)
/IO10: J8.13, U1.13 (GPIO10)
/IO11: J8.14, U1.14 (GPIO11)
/IO12: J7.1, U1.15 (GPIO12)
/IO13: J7.2, U1.16 (GPIO13)
/IO14: J7.3, U1.17 (GPIO14)
/IO15: J7.4, U1.18 (GPIO15)
/IO16: J7.13
/IO17: J7.14
/IO18: J6.1
/IO19: J6.2
/IO20: J6.3
/IO21: J6.4
/IO22: J6.6, R14.2, SW3.2, U1.34 (GPIO22)
/IO23: J6.7, R15.2, SW4.2, U1.35 (GPIO23)
/IO24: J6.8, U1.36 (GPIO24)
/IO25: J6.9, R16.2, SW5.2, U1.37 (GPIO25)
/IOVDD: J6.5, J6.14, J7.8, J8.1, J8.10, J9.7
/QSPI_SCLK: J9.10, U1.52 (QSPI_SCLK), U5.6 (CLK)
/QSPI_SD0: J9.11, U1.53 (QSPI_SD0), U5.5 (DI/IO_{0})
/QSPI_SD1: J9.13, U1.55 (QSPI_SD1), U5.2 (DO/IO_{1})
/QSPI_SD2: J9.12, U1.54 (QSPI_SD2), U5.3 (~WP/IO_{2})
/QSPI_SD3: J9.9, U1.51 (QSPI_SD3), U5.7 (~HOLD/~RESET/IO_{3})
/QSPI_SS: J9.14, R11.2, SW2.2, U1.56 (~QSPI_SS), U5.1 (~CS)
/RED: J3.1, R7.2
/RUN: J7.12
/SWDIO: J7.11, U1.25 (SWDIO)
/SW_CLK: J7.10, U1.24 (SWCLK)
/TESTEN: J7.5
/USB_D+: D7.3 (K), J1.A6 (D+), J1.B6 (D+), J4.3 (D+), R12.1
/USB_D-: D7.2 (K), J1.A7 (D-), J1.B7 (D-), J4.2 (D-), R13.1
/USB_DM: J9.4
/USB_DP: J9.5
/USB_VDD: J9.6
/VREG_VIN: J9.2
/VREG_VOUT: J9.3
/VSYNC: J3.14, U1.28 (GPIO17)
/XIN: C12.2, J7.6, U1.20 (XIN), Y1.1
/XOUT: J7.7, R5.2, U1.21 (XOUT)
GND: C1.2, C3.2, C6.2, C7.2, C8.1, C9.2, C11.2, C12.1, C13.1, C14.2, D1.1 (K), D2.1 (K), D7.1 (A), J1.A1 (GND), J1.A12 (GND), J1.B1 (GND), J1.B12 (GND), J1.SH (SHIELD), J3.5, J3.6, J3.7, J3.8, J3.10, J3.SH, J4.4 (GND), J4.SH1 (SHIELD), J4.SH2 (SHIELD), R2.2, R3.2, SW2.1, SW3.1, SW4.1, SW5.1, U1.19 (TESTEN), U1.57 (GND), U2.1 (GND), U5.4 (GND), Y1.2 (G), Y1.4 (G)
unnamed: C13.2, R5.1, Y1.3
unnamed: D1.2 (A), R6.1
unnamed: D2.2 (A), R17.1
unnamed: J1.A5 (CC1), R2.1
unnamed: J1.B5 (CC2), R3.1
unnamed: R7.1, U1.29 (GPIO18)
unnamed: R8.1, U1.30 (GPIO19)
unnamed: R9.1, U1.31 (GPIO20)
unnamed: R10.1, U1.32 (GPIO21)
unnamed: R13.2, U1.46 (USB_DM)
unnamed: R12.2, U1.47 (USB_DP)
unnamed: C10.2, U1.45 (VREG_VOUT)

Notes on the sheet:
QSPI FLASH MEMORY
USB TYPE A
VOLTAGE REGULATOR
HEADERS
RP2040
VGA CONNECTOR
CRYSTAL OSCILLATOR
USB TYPE C
PUSH BUTTONS
PICOLINK SCHEMATIC

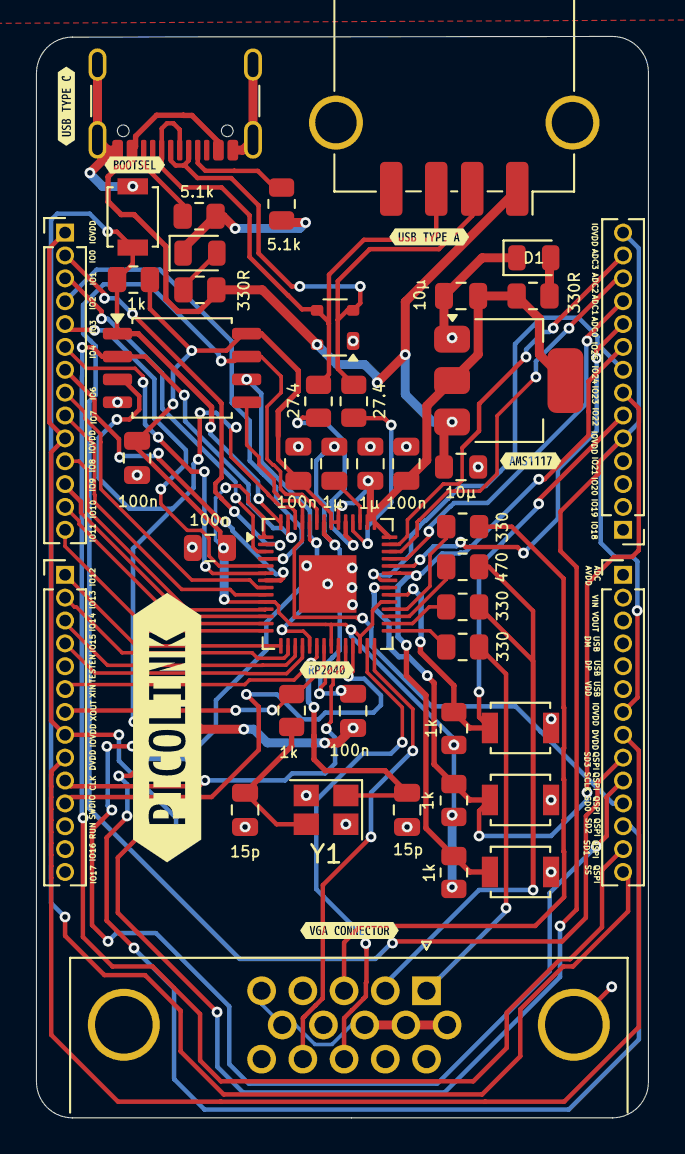
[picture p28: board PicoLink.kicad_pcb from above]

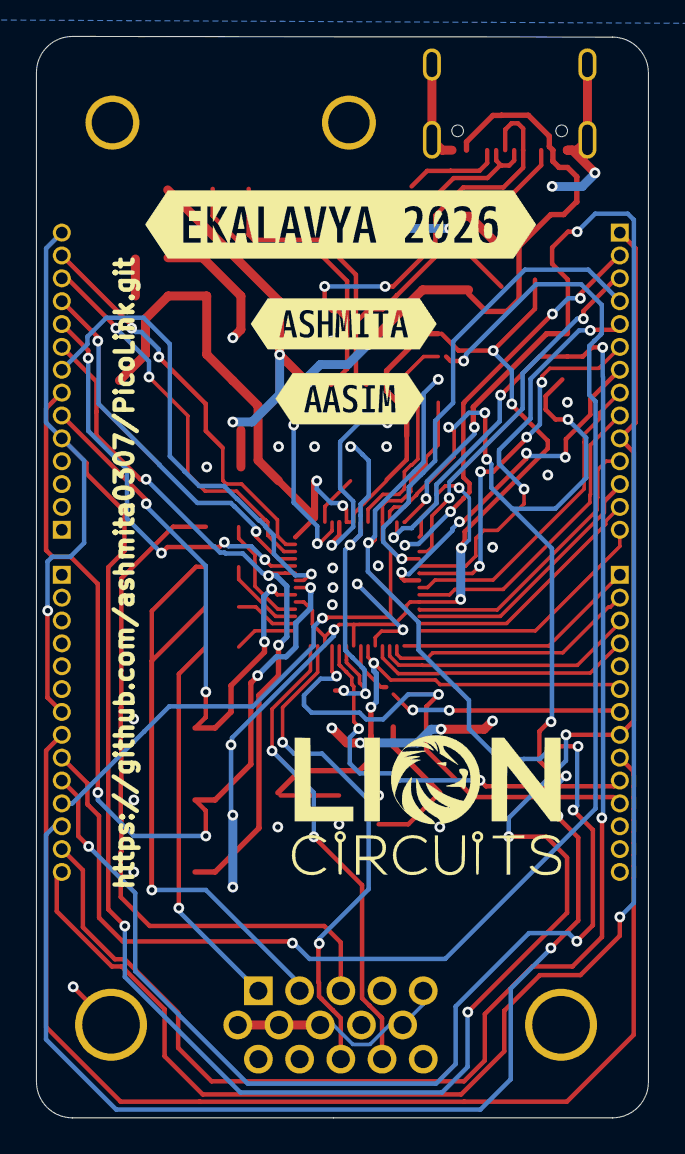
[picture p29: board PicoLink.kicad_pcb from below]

Board: 2 copper layers, 34.0 x 60.1 mm, 54 parts (3 on the bottom side), 59 nets.

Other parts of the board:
kibuzzard-6A7FFBEB: G***; kibuzzard-6A7FFBEB
kibuzzard-6A7FFF5E: G***; kibuzzard-6A7FFF5E
kibuzzard-6A7FFF8E: G***; kibuzzard-6A7FFF8E
kibuzzard-6A7FFF22: G***; kibuzzard-6A7FFF22
kibuzzard-6A7FFF38: G***; kibuzzard-6A7FFF38
kibuzzard-6A7FFFF4: G***; kibuzzard-6A7FFFF4
kibuzzard-6A81CC8C: G***; kibuzzard-6A81CC8C
kibuzzard-6A81CC73: G***; kibuzzard-6A81CC73
kibuzzard-6A81CC96: G***; kibuzzard-6A81CC96
kibuzzard-6A80000C: G***; kibuzzard-6A80000C

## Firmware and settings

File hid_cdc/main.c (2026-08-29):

#include <stdio.h>
#include <string.h>

#include "bsp/board_api.h"
#include "tusb.h"
#include "usb_descriptors.h"

enum
{
    BLINK_NOT_MOUNTED = 250,
    BLINK_MOUNTED     = 1000,
    BLINK_SUSPENDED   = 2500,
};

static uint32_t blink_interval_ms = BLINK_NOT_MOUNTED;

static const uint8_t picolink[] =
{
    HID_KEY_P,
    HID_KEY_I,
    HID_KEY_C,
    HID_KEY_O,
    HID_KEY_L,
    HID_KEY_I,
    HID_KEY_N,
    HID_KEY_K
};

static uint8_t picolink_index = 0;

static bool button_was_pressed = false;
static bool key_pressed = false;

void led_blinking_task(void);
void hid_task(void);

int main(void)
{
    board_init();

    const tusb_rhport_init_t rh_init =
    {
        .role  = TUSB_ROLE_DEVICE,
        .speed = TUSB_SPEED_FULL
    };

    TU_ASSERT(tud_rhport_init(BOARD_TUD_RHPORT, &rh_init));

    board_init_after_tusb();

    while (1)
    {
        tud_task();

      
        if (tud_cdc_available())
        {
            char buf[64];

            uint32_t count = tud_cdc_read(buf, sizeof(buf));

            if (count > 0)
            {
                tud_cdc_write(buf, count);
                tud_cdc_write_flush();
            }
        }

        hid_task();
        led_blinking_task();
    }

    return 0;
}


void tud_mount_cb(void)
{
    blink_interval_ms = BLINK_MOUNTED;
}

void tud_umount_cb(void)
{
    blink_interval_ms = BLINK_NOT_MOUNTED;
}

void tud_suspend_cb(bool remote_wakeup_en)
{
    (void) remote_wakeup_en;

    blink_interval_ms = BLINK_SUSPENDED;
}

void tud_resume_cb(void)
{
    blink_interval_ms =
        tud_mounted()
        ? BLINK_MOUNTED
        : BLINK_NOT_MOUNTED;
}



void tud_cdc_rx_cb(uint8_t itf)
{
    (void) itf;
}



void hid_task(void)
{
    const uint32_t interval_ms = 10;

    static uint32_t start_ms = 0;

    if (board_millis() - start_ms < interval_ms)
    {
        return;
    }

    start_ms += interval_ms;

    bool button_pressed = board_button_read();



    if (button_pressed && !button_was_pressed)
    {

        if (tud_hid_ready() && !key_pressed)
        {
            uint8_t keycode[6] = {0};

            keycode[0] = picolink[picolink_index];

            tud_hid_keyboard_report(
                REPORT_ID_KEYBOARD,
                0,
                keycode
            );

            key_pressed = true;
        }
    }

    button_was_pressed = button_pressed;
}


void tud_hid_report_complete_cb(
    uint8_t instance,
    uint8_t const* report,
    uint16_t len
)
{
    (void) instance;
    (void) report;
    (void) len;


    if (key_pressed)
    {
        tud_hid_keyboard_report(
            REPORT_ID_KEYBOARD,
            0,
            NULL
        );

        key_pressed = false;

   
        picolink_index++;

        if (picolink_index >= sizeof(picolink))
        {
            picolink_index = 0;
        }
    }
}

uint16_t tud_hid_get_report_cb(
    uint8_t instance,
    uint8_t report_id,
    hid_report_type_t report_type,
    uint8_t* buffer,
    uint16_t reqlen
)
{
    (void) instance;
    (void) report_id;
    (void) report_type;
    (void) buffer;
    (void) reqlen;

    return 0;
}

void tud_hid_set_report_cb(
    uint8_t instance,
    uint8_t report_id,
    hid_report_type_t report_type,
    uint8_t const* buffer,
    uint16_t bufsize
)
{
    (void) instance;

    if (report_type == HID_REPORT_TYPE_OUTPUT)
    {
        if (report_id == REPORT_ID_KEYBOARD)
        {
            if (bufsize < 1)
            {
                return;
            }

            uint8_t const kbd_leds = buffer[0];

            if (kbd_leds & KEYBOARD_LED_CAPSLOCK)
            {
                blink_interval_ms = 0;
                board_led_write(true);
            }
            else
            {
                board_led_write(false);
                blink_interval_ms = BLINK_MOUNTED;
            }
        }
    }
}

void led_blinking_task(void)
{
    static uint32_t start_ms = 0;
    static bool led_state = false;

    if (!blink_interval_ms)
    {
        return;
    }
    if (board_millis() - start_ms < blink_interval_ms)
    {
        return;
    }
    start_ms += blink_interval_ms;
    board_led_write(led_state);
    led_state = !led_state;
}

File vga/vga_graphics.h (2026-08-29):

/**
 *   CODIGO ORIGINAL BY Hunter Adams (vha3@cornell.edu)
 *   Modificado by San Tarcisio (https://instagram.com)
 *   Modificado para 16 Cores (4-bits 1:2:1 R-G-B Layout)
 * 
 * HARDWARE CONNECTIONS
 *  - GPIO 16 ---> VGA Hsync
 *  - GPIO 17 ---> VGA Vsync
 *  - GPIO 18 ---> 330 ohm resistor ---> VGA Red
 *  - GPIO 19 ---> 330 ohm resistor ---> VGA Green (MSB - Bright Green)
 *  - GPIO 20 ---> 680 ohm resistor ---> VGA Green (LSB - Dim Green)
 *  - GPIO 21 ---> 330 ohm resistor ---> VGA Blue
 *  - RP2040 GND ---> VGA GND
 *
 * NOTE
 *  - Connect the outputs of GPIO 19 and GPIO 20 together 
 *    AFTER their respective resistors to feed into the VGA Green Pin.
 */

#pragma once
#include <stdint.h>

// I/O Pin names updated for sequential 4-bit output layout
enum vga_pins {
    HSYNC = 16, 
    VSYNC, 
    RED_PIN,        // GPIO 18 (Bit 0)
    GREEN_MSB_PIN,  // GPIO 19 (Bit 1)
    GREEN_LSB_PIN,  // GPIO 20 (Bit 2)
    BLUE_PIN        // GPIO 21 (Bit 3)
};

// 16 Custom colors mapped to 4-bit hardware binary configurations (B G0 G1 R)
enum colors {
    BLACK          = 0b0000,
    RED            = 0b0001,

    GREEN_DIM      = 0b0100, // Green LSB only
    GREEN_MEDIUM   = 0b0010, // Green MSB only
    GREEN_BRIGHT   = 0b0110, // Both Green pins combined

    BLUE           = 0b1000,

    // Combined shades
    CYAN_DIM       = 0b1100, // Blue + Green Dim
    CYAN_BRIGHT    = 0b1110, // Blue + Full Green
    MAGENTA        = 0b1001, // Blue + Red
    YELLOW_DIM     = 0b0101, // Red + Green Dim
    YELLOW_BRIGHT  = 0b0111, // Red + Full Green
    ORANGE         = 0b0011, // Red + Green Medium

    // Light / Dark variations
    DARK_GRAY      = 0b1010,
    LIGHT_GRAY     = 0b1101,
    PINK           = 0b1011,

    WHITE          = 0b1111  // All pins active
};
// Screen width/height
#define screenWidth 640 // in pixels
#define screenHeight 480 // in pixels

extern unsigned char vga_data_array[];
extern volatile uint32_t currentFrame;  // frame counter

// VGA primitives - usable in main
void initVGA(void);
void clearScreen(void);
void nextFrame(void);
void drawPixel(short x, short y, char color);
void drawVLine(short x, short y, short h, char color);
void drawHLine(short x, short y, short w, char color);
void drawLine(short x0, short y0, short x1, short y1, char color);
void drawRect(short x, short y, short w, short h, char color);
void drawRectCenter(short x, short y, short w, short h, char color);
void drawCircle(short x0, short y0, short r, char color);
void drawCircleHelper(short x0, short y0, short r, unsigned char cornername, char color);
void fillCircle(short x0, short y0, short r, char color);
void fillCircleHelper(short x0, short y0, short r, unsigned char cornername, short delta, char color);
void drawRoundRect(short x, short y, short w, short h, short r, char color);
void fillRoundRect(short x, short y, short w, short h, short r, char color);
void fillRect(short x, short y, short w, short h, char color);
void drawChar(short x, short y, unsigned char c, char color, char bg, unsigned char size);
void setTextCursor(short x, short y);
void setTextColor(char c);
void setTextColor2(char c, char bg);
void setTextSize(unsigned char s);
void setTextWrap(char w);
void tft_write(unsigned char c);
void writeString(char* str);
void drawSprite(short x, short y, const uint8_t* sprite, char color, int scale);

extern const uint8_t player_sprite[8];
extern const uint8_t alien_sprite[8];

// conways
int getPixel(short x, short y);

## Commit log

2026-08-29 PCB FILES ADDED
    [PicoLink.kicad_pcb, PicoLink.kicad_sch]
2026-08-30 README Updated
    Removed a broken link to the PICO-VGA-BOARD GitHub repository.
